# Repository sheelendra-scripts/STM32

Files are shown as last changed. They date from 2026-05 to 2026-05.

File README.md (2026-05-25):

# STM32

Compact STM32F103C8T6 controller board designed in KiCad, with USB power and native USB data lines broken out on PA11/PA12. The design includes on-board 3.3 V regulation, external 16 MHz crystal, filtered analog supply (VDDA), BOOT0 selection, and headers for SWD, UART1, and I2C2. Use it as a reference design or a starting point for custom STM32 hardware.

## Highlights

- Complete KiCad project: schematic, PCB, and project files
- Manufacturing-ready outputs (Gerbers, drill files, and pick-and-place)
- 3D model included for enclosure fit checks

## Preview

### 3D View

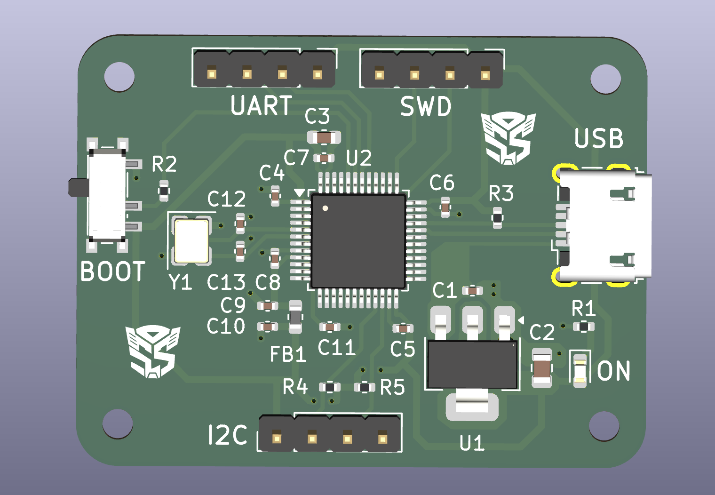
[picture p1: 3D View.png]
3D View


### PCB Layout

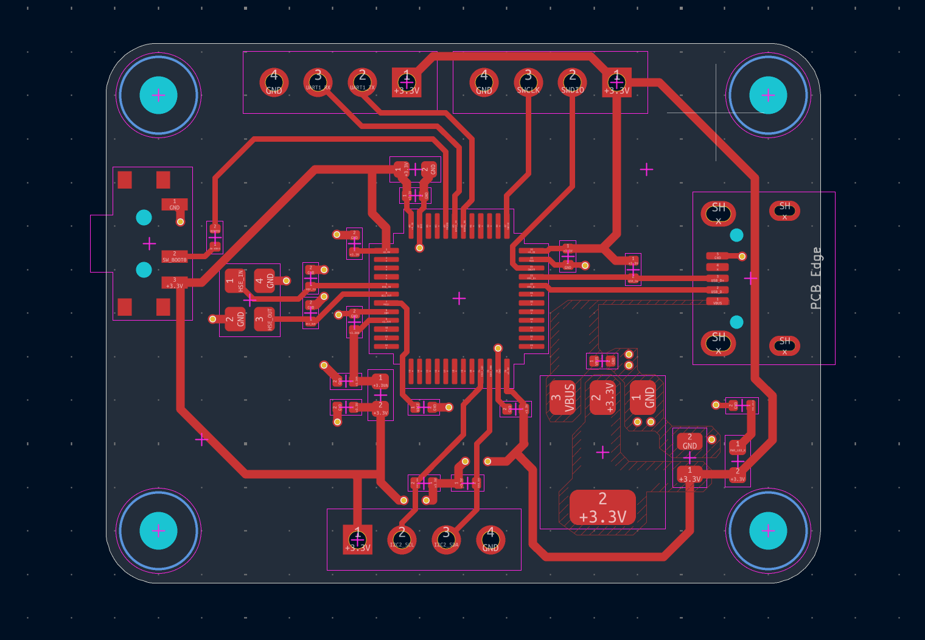
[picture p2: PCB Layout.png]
PCB Layout


### PCB Schematic

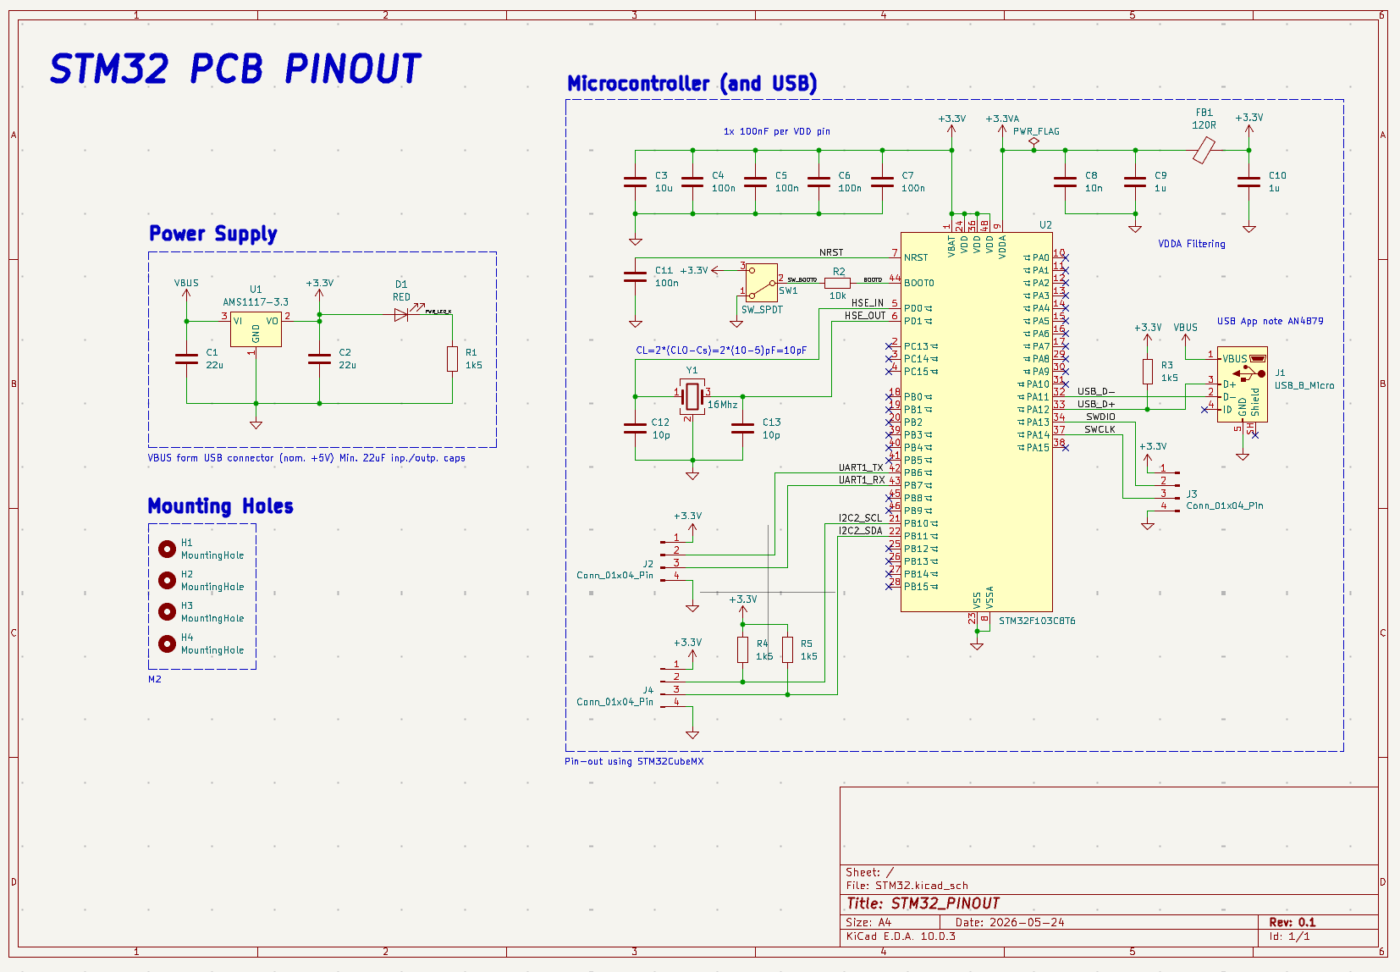
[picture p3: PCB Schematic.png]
PCB Schematic


## What is in this repo

- KiCad source files: schematic, PCB, and project settings
- Mechanical model: STEP file for enclosure alignment
- Manufacturing outputs: Gerbers, drill file, and component placement CSVs
- Reference renders: 3D view, layout, and schematic images

## File labels

| File | Label |
| --- | --- |
| [STM32.kicad_sch](STM32.kicad_sch) | Schematic source |
| [STM32.kicad_pcb](STM32.kicad_pcb) | PCB layout source |
| [STM32.kicad_pro](STM32.kicad_pro) | KiCad project settings |
| [STM32.kicad_prl](STM32.kicad_prl) | KiCad local settings |
| [629105150521 (rev1).stp](629105150521%20(rev1).stp) | 3D mechanical model |
| [3D View.png](3D%20View.png) | 3D render |
| [PCB Layout.png](PCB%20Layout.png) | PCB layout render |
| [PCB Schematic.png](PCB%20Schematic.png) | Schematic render |
| [Manufacturing/STM32.csv](Manufacturing/STM32.csv) | Component list export |
| [Manufacturing/STM32-all-pos.csv](Manufacturing/STM32-all-pos.csv) | Pick-and-place positions |
| [Manufacturing/Gerber/](Manufacturing/Gerber/) | Gerber and drill outputs |
| [README.md](README.md) | Project overview |

## Hardware overview

- Power: USB VBUS into AMS1117-3.3 with bulk input/output caps and a power LED
- Clocking: 16 MHz crystal with load capacitors on HSE
- Boot/reset: BOOT0 SPDT switch, pull resistor, and NRST capacitor
- USB: D+ and D- on PA12/PA11 with 1.5 k pull-up on D+
- Debug: 1x4 SWD header (3.3 V, SWDIO, SWCLK, GND)
- IO headers: UART1 and I2C2 (with pull-ups) on 1x4 headers
- Mechanical: four M2 mounting holes

## Schematic description

- Core MCU: STM32F103C8T6 (U2) with dedicated VDD decoupling (multiple 100 nF caps plus a bulk 10 uF). NRST has a 100 nF cap to ground, and BOOT0 is selectable via a small SPDT switch with a pull resistor.
- Clocking: External 16 MHz crystal (Y1) on HSE_IN/HSE_OUT with two 10 pF load capacitors to ground.
- Power supply: USB VBUS feeds an AMS1117-3.3 LDO with 22 uF input/output caps. A red power LED with a series resistor indicates 3.3 V presence.
- Analog supply filtering: VDDA is isolated from 3.3 V using a ferrite bead and local 10 nF + 1 uF caps, plus a 1 uF cap on VDDA.
- USB interface: Micro-USB connector routes D+/D- to PA12/PA11. A 1.5 k pull-up on D+ provides full-speed identification, with VBUS present for USB power/sense.
- Headers: SWD header with 3.3 V, SWDIO, SWCLK, and GND. UART header (USART1 TX/RX) with 3.3 V and GND. I2C header (I2C2 SCL/SDA) with 3.3 V and GND, plus 1.5 k pull-ups.
- Mechanical: Four M2 mounting holes (H1-H4).

## Bill of materials (BOM)

Values are taken from the schematic. Confirm footprints and ratings before ordering.

| Ref(s) | Qty | Value / Part | Notes |
| --- | --- | --- | --- |
| U2 | 1 | STM32F103C8T6 | LQFP-48 MCU |
| U1 | 1 | AMS1117-3.3 | 5 V to 3.3 V LDO |
| Y1 | 1 | 16 MHz crystal | HSE clock |
| C1, C2 | 2 | 22 uF | LDO input/output bulk |
| C3 | 1 | 10 uF | VDD bulk |
| C4, C5, C6, C7 | 4 | 100 nF | VDD decoupling (one per VDD pin) |
| C8 | 1 | 10 nF | VDDA filter |
| C9, C10 | 2 | 1 uF | VDDA filtering |
| C11 | 1 | 100 nF | NRST cap |
| C12, C13 | 2 | 10 pF | Crystal load caps |
| FB1 | 1 | Ferrite bead, 120 R | VDDA filter |
| D1 | 1 | Red LED | Power indicator |
| R1 | 1 | 1.5 k | LED series resistor |
| R2 | 1 | 10 k | BOOT0 pull |
| R3 | 1 | 1.5 k | USB D+ pull-up |
| R4, R5 | 2 | 1.5 k | I2C pull-ups |
| SW1 | 1 | SPDT switch | BOOT0 select |
| J1 | 1 | Micro-USB B receptacle | USB + power |
| J2 | 1 | 1x4 header | UART1 header |
| J3 | 1 | 1x4 header | SWD header |
| J4 | 1 | 1x4 header | I2C2 header |
| H1, H2, H3, H4 | 4 | M2 mounting holes | Mechanical |

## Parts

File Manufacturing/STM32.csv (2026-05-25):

Reference | Qty | Value | DNP | Exclude from BOM | Exclude from Board | Footprint | Datasheet
C1 | 1 | 22u |  |  |  | Capacitor_SMD:C_0402_1005Metric
C2 | 1 | 22u |  |  |  | Capacitor_SMD:C_0805_2012Metric
C3 | 1 | 10u |  |  |  | Capacitor_SMD:C_0603_1608Metric
C4,C5,C6,C7,C11 | 5 | 100n |  |  |  | Capacitor_SMD:C_0402_1005Metric
C8 | 1 | 10n |  |  |  | Capacitor_SMD:C_0402_1005Metric
C9,C10 | 2 | 1u |  |  |  | Capacitor_SMD:C_0402_1005Metric
C12,C13 | 2 | 10p |  |  |  | Capacitor_SMD:C_0402_1005Metric
D1 | 1 | RED |  |  |  | LED_SMD:LED_0603_1608Metric
FB1 | 1 | 120R |  |  |  | Inductor_SMD:L_0603_1608Metric
J1 | 1 | USB_B_Micro |  |  |  | Connector_USB:USB_Micro-B_Wuerth_629105150521
J2,J3,J4 | 3 | Conn_01x04_Pin |  |  |  | Connector_PinHeader_2.54mm:PinHeader_1x04_P2.54mm_Vertical
R1,R3,R4,R5 | 4 | 1k5 |  |  |  | Resistor_SMD:R_0402_1005Metric
R2 | 1 | 10k |  |  |  | Resistor_SMD:R_0402_1005Metric
SW1 | 1 | SW_SPDT |  |  |  | Button_Switch_SMD:SW_SPDT_PCM12
U1 | 1 | AMS1117-3.3 |  |  |  | Package_TO_SOT_SMD:SOT-223-3_TabPin2 | http://www.advanced-monolithic.com/pdf/ds1117.pdf
U2 | 1 | STM32F103C8T6 |  |  |  | Package_QFP:LQFP-48_7x7mm_P0.5mm | https://www.st.com/resource/en/datasheet/stm32f103c8.pdf
Y1 | 1 | 16Mhz |  |  |  | Crystal:Crystal_SMD_3225-4Pin_3.2x2.5mm

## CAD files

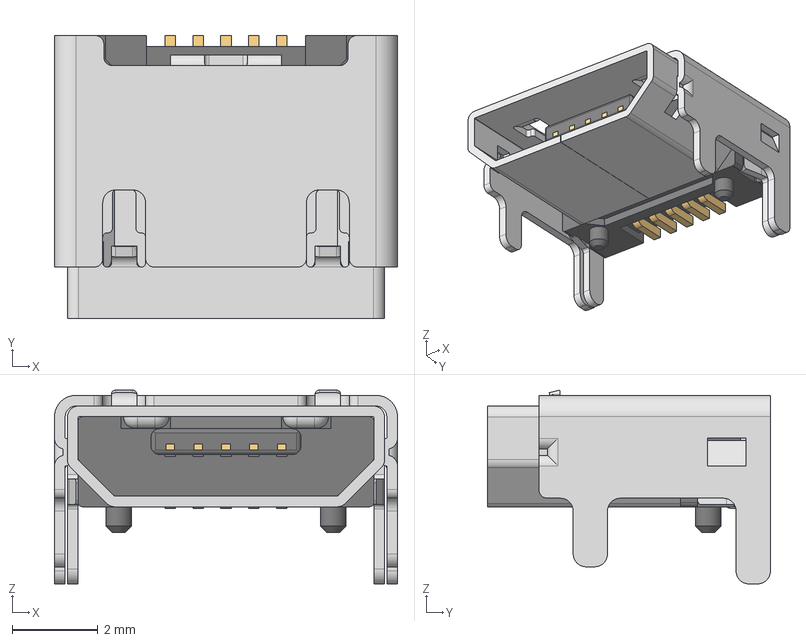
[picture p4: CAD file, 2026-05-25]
629105150521 (rev1).stp
8.00 x 6.60 x 4.52 mm
629105150521_Housing
629105150521_Pin1 x 4
629105150521_Pin2
629105150521_Shielding2
629105150521_Shielding

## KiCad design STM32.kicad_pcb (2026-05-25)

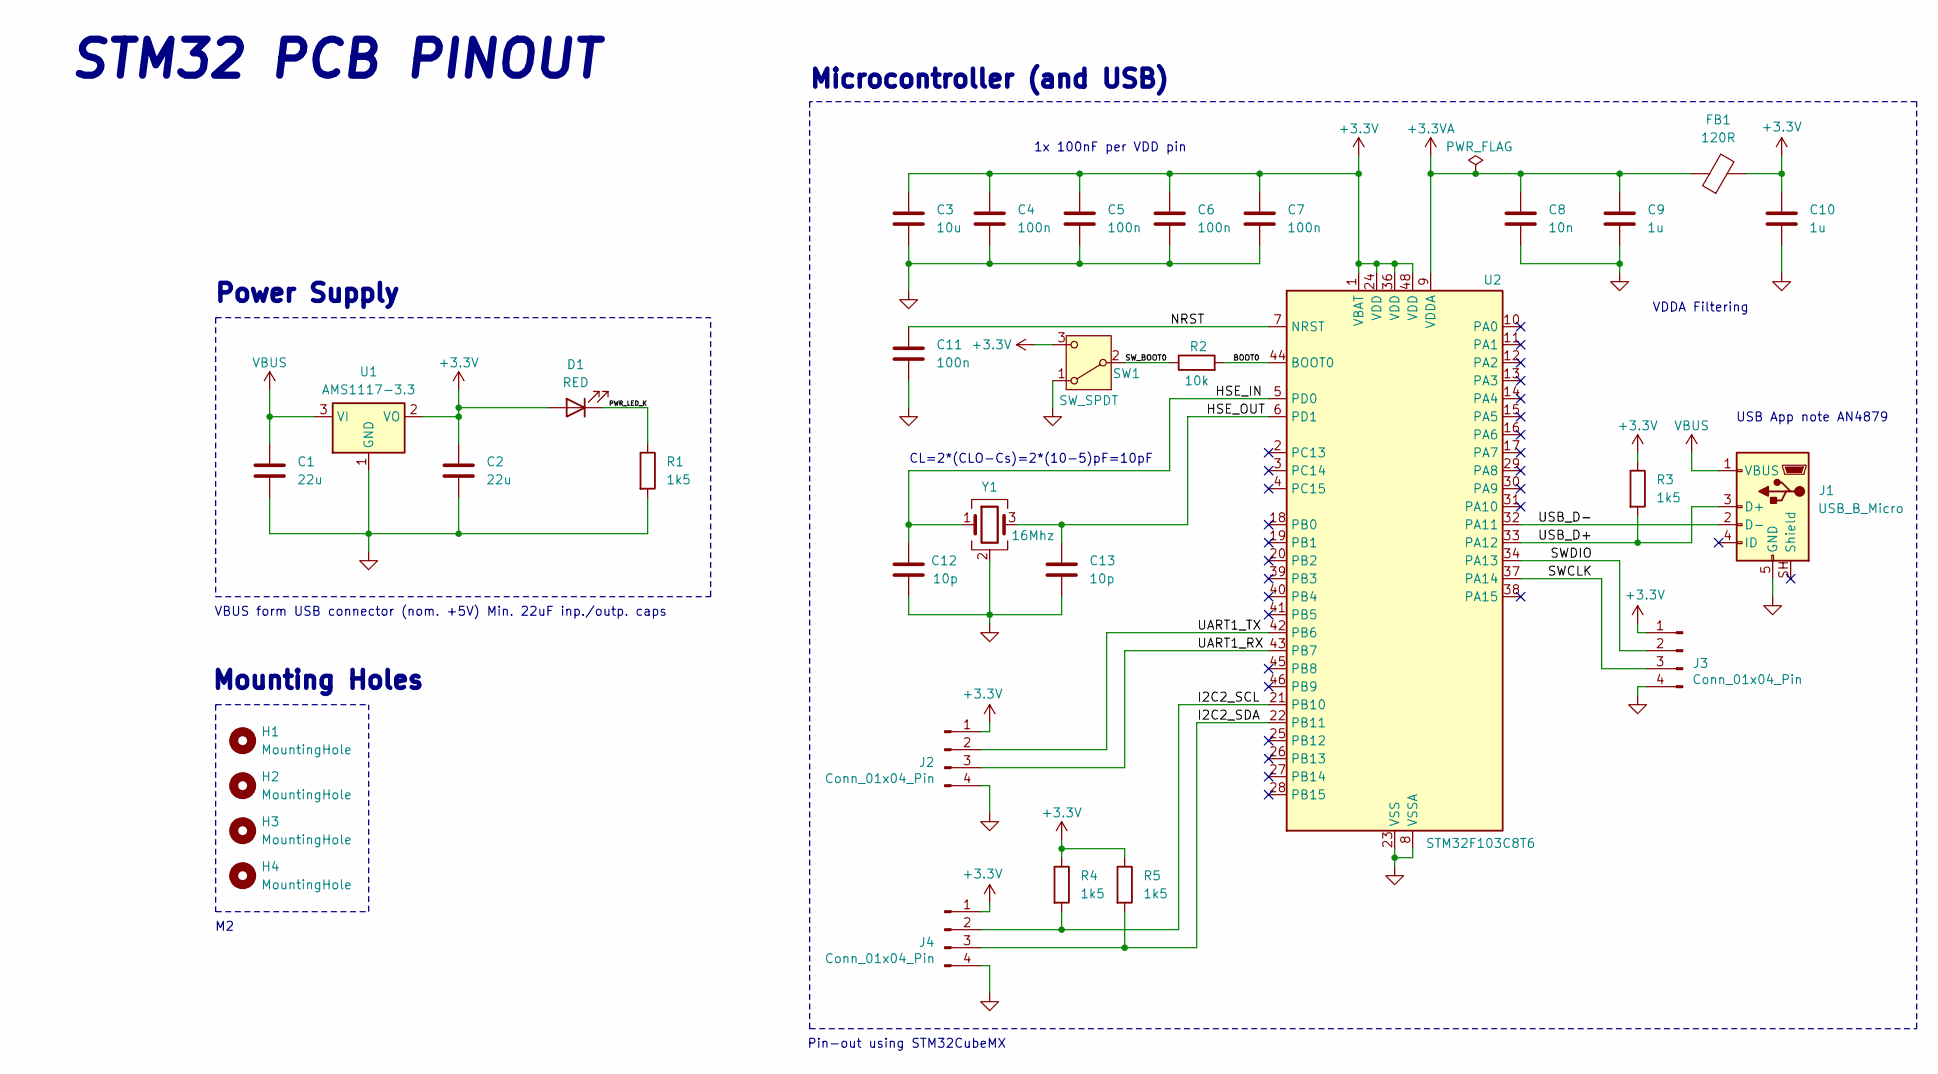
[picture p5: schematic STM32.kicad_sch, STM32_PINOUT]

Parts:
C1: 22u; C_0402_1005Metric
C2: 22u; C_0805_2012Metric
C3: 10u; C_0603_1608Metric
C4, C5, C6, C7, C11: 100n; C_0402_1005Metric
C8: 10n; C_0402_1005Metric
C9, C10: 1u; C_0402_1005Metric
C12, C13: 10p; C_0402_1005Metric
D1: RED; LED_0603_1608Metric
FB1: 120R; L_0603_1608Metric
H1, H2, H3, H4: MountingHole; MountingHole_2.2mm_M2
J1: USB_B_Micro; USB_Micro-B_Wuerth_629105150521
J2, J3, J4: Conn_01x04_Pin; PinHeader_1x04_P2.54mm_Vertical
R1, R3, R4, R5: 1k5; R_0402_1005Metric
R2: 10k; R_0402_1005Metric
SW1: SW_SPDT; SW_SPDT_PCM12
U1: AMS1117-3.3; SOT-223-3_TabPin2
U2: STM32F103C8T6; LQFP-48_7x7mm_P0.5mm
Y1: 16Mhz; Crystal_SMD_3225-4Pin_3.2x2.5mm

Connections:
+3.3V: C2.1, C3.1, C4.1, C5.1, C6.1, C7.1, C10.1, D1.2 (A), FB1.2, J2.1, J3.1, J4.1, R3.1, R4.1, R5.1, SW1.3 (C), U1.2 (VO), U2.1 (VBAT), U2.24 (VDD), U2.36 (VDD), U2.48 (VDD)
+3.3VA: C8.1, C9.1, FB1.1, U2.9 (VDDA)
/BOOT0: R2.2, U2.44 (BOOT0)
/HSE_IN: C12.1, U2.5 (PD0), Y1.1
/HSE_OUT: C13.1, U2.6 (PD1), Y1.3
/I2C2_SCL: J4.2, R4.2, U2.21 (PB10)
/I2C2_SDA: J4.3, R5.2, U2.22 (PB11)
/NRST: C11.1, U2.7 (NRST)
/PWR_LED_K: D1.1 (K), R1.1
/SWCLK: J3.3, U2.37 (PA14)
/SWDIO: J3.2, U2.34 (PA13)
/SW_BOOT0: R2.1, SW1.2 (B)
/UART1_RX: J2.3, U2.43 (PB7)
/UART1_TX: J2.2, U2.42 (PB6)
/USB_D+: J1.3 (D+), R3.2, U2.33 (PA12)
/USB_D-: J1.2 (D-), U2.32 (PA11)
GND: C1.2, C2.2, C3.2, C4.2, C5.2, C6.2, C7.2, C8.2, C9.2, C10.2, C11.2, C12.2, C13.2, J1.5 (GND), J2.4, J3.4, J4.4, R1.2, SW1.1 (A), U1.1 (GND), U2.8 (VSSA), U2.23 (VSS), U2.35 (VSS), U2.47 (VSS), Y1.2 (G), Y1.4 (G)
VBUS: C1.1, J1.1 (VBUS), U1.3 (VI)

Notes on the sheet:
STM32 PCB PINOUT
USB App note AN4879
VDDA Filtering
Microcontroller (and USB)
Pin-out using STM32CubeMX
CL=2*(CLO-Cs)=2*(10-5)pF=10pF
Power Supply
VBUS form USB connector (nom. +5V) Min. 22uF inp./outp. caps
1x 100nF per VDD pin
Mounting Holes

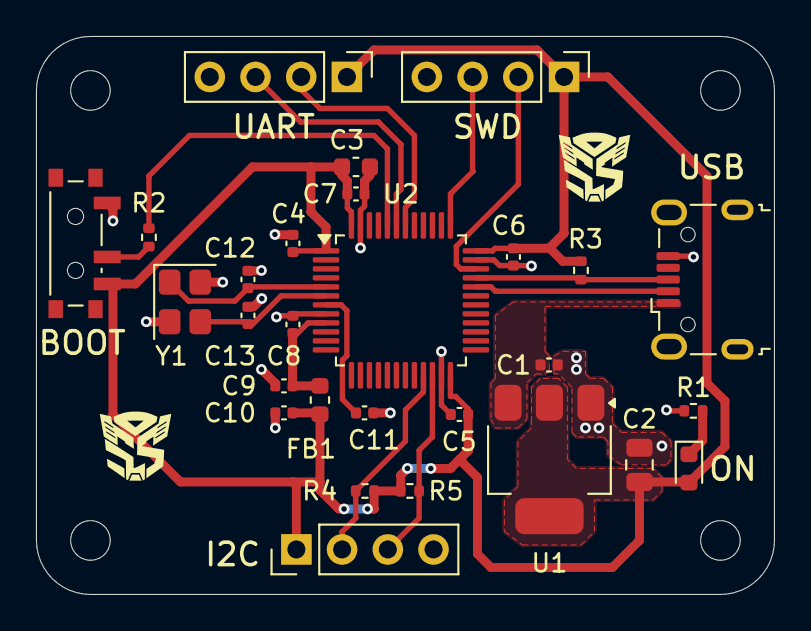
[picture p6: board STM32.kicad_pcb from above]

Board: 2 copper layers, 41.0 x 31.0 mm, 32 parts (0 on the bottom side), 18 nets.
